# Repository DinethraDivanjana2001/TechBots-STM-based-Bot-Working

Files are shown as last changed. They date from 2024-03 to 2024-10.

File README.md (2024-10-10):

# TechBots-Bot-Working

### Introduction

Our robot was designed to compete in the **Sri Lankan Robotics Challenge 2024**. The robot utilizes a **Raspberry Pi 4B** for color detection and alignment, while the main control logic is handled by an **STM32 microcontroller**. The project combines various hardware and software components to achieve precise control and functionality.

The repository contains the codes used for the microcontroller, the Raspberry Pi, schematics, PCB Design, and 3D enclosure design.

The robot is capable of the following tasks:
* Line detection and following
* Wall color detection
* Floor color detection
* Object detection between a cube and a cylinder
* Shooting a ball into a target

The robot is entirely autonomous.

### Codes

The code for the microcontroller is found under the **STM32 Firmware** directory. There are two versions: one using an **STM32 microcontroller** and the other using an **ESP32**. These codes handle sensor readings and control the robot's movement by controlling the motors.

The **Raspberry Pi Firmware** directory contains the code for color detection and aligning the robot with its target.

### PCB Design

The schematics and PCB design files are found under the **PCB Design** directory. This includes schematics for subcircuits. The robot's PCB is a **4-layer design**.

### Shooter Mechanism

The shooter mechanism is responsible for launching balls into the target. The design, along with related control code, is provided in the **Shooter Mechanism** folder.

### 3D Models

The **3D Models** and renders of the robot are  located in the **3D Designs** directory. The full assembly of the robot is also included.

### Images

Add your images to the appropriate sections below:

1. Robot Design:
   
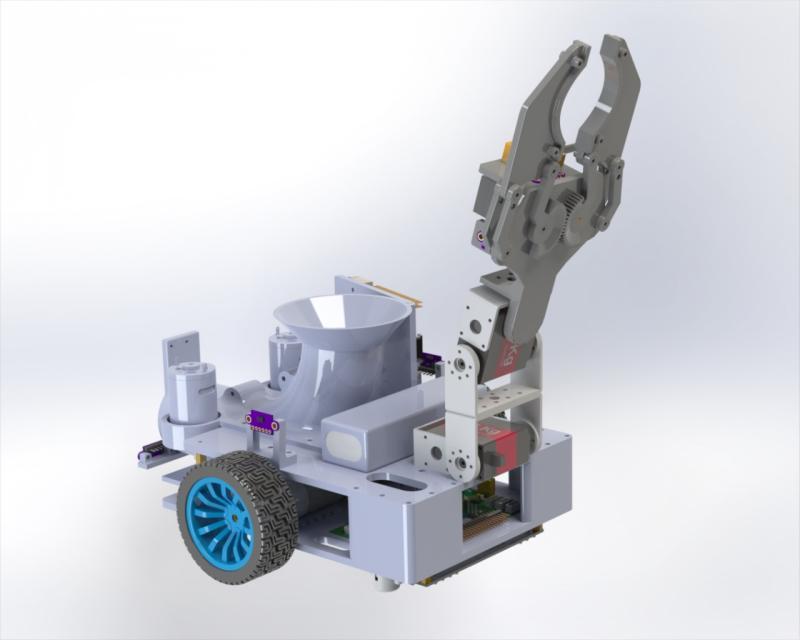
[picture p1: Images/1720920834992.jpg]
Robot Design
   

2. PCB Design:

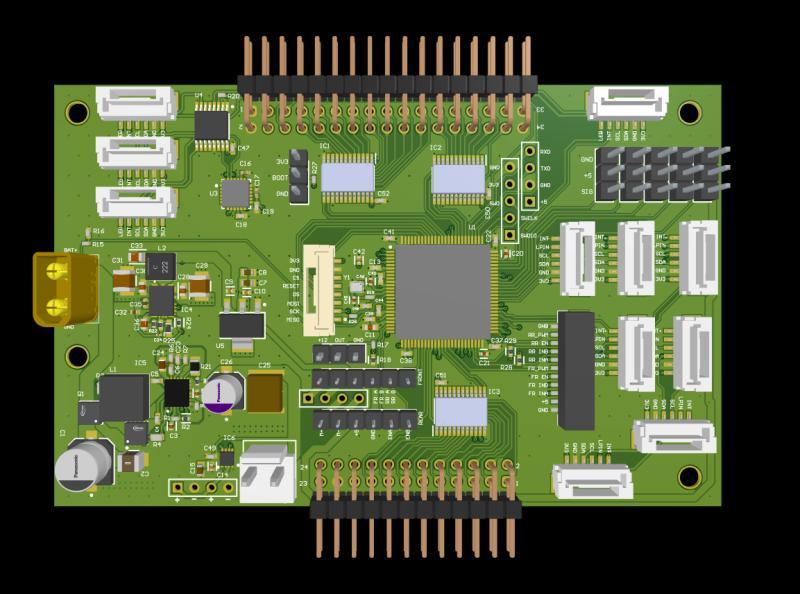
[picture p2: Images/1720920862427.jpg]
PCB Design
   

3. Shooter Mechanism:

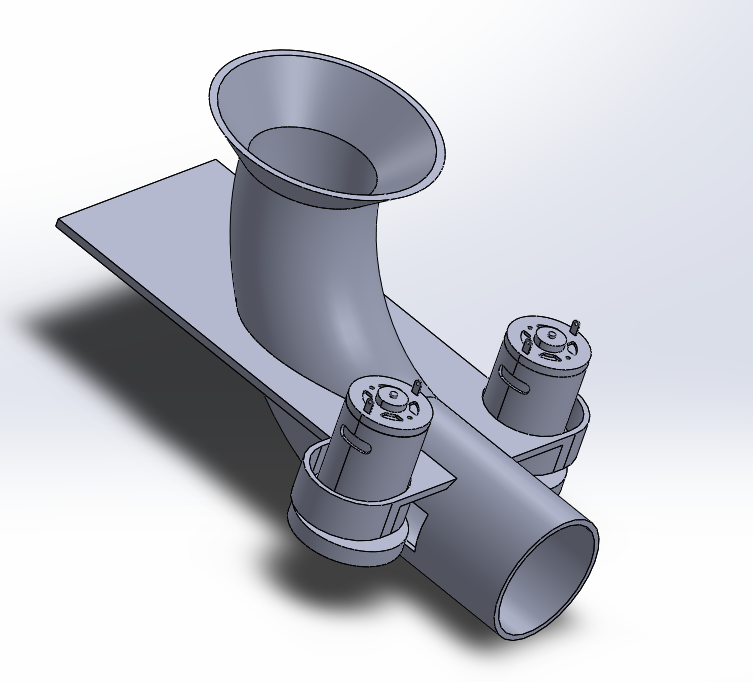
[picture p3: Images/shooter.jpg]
Shooter Mechanism


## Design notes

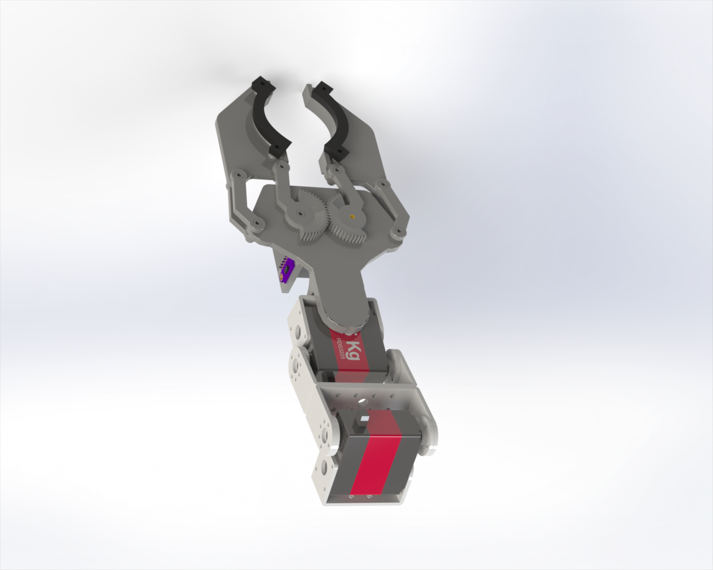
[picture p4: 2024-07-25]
3D designs/3D Renders/Arm bottom.png

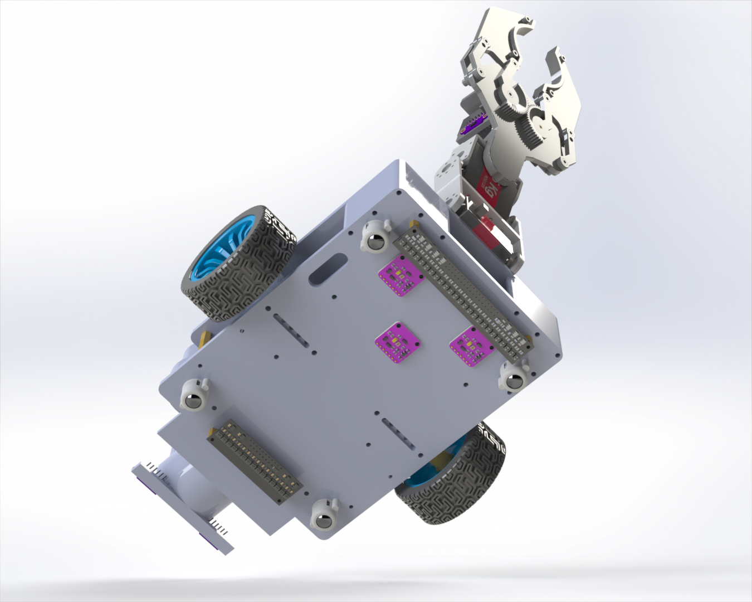
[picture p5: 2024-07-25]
3D designs/3D Renders/Bottom view.png

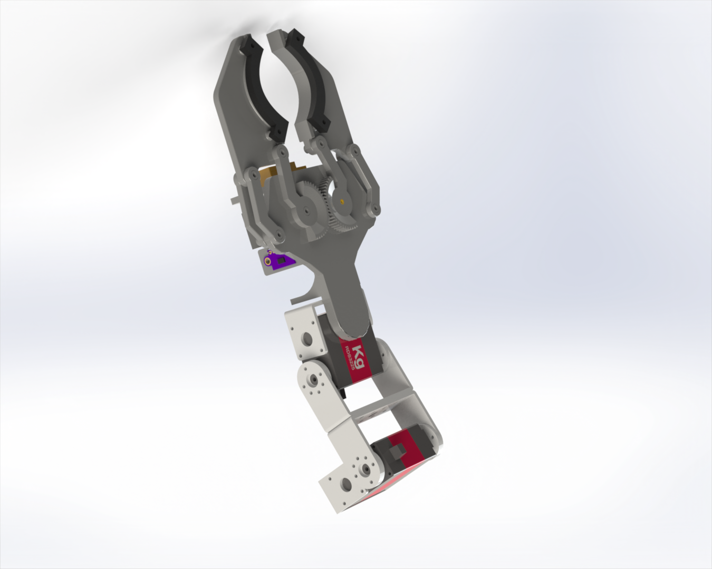
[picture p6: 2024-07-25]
3D designs/3D Renders/Arm side.png

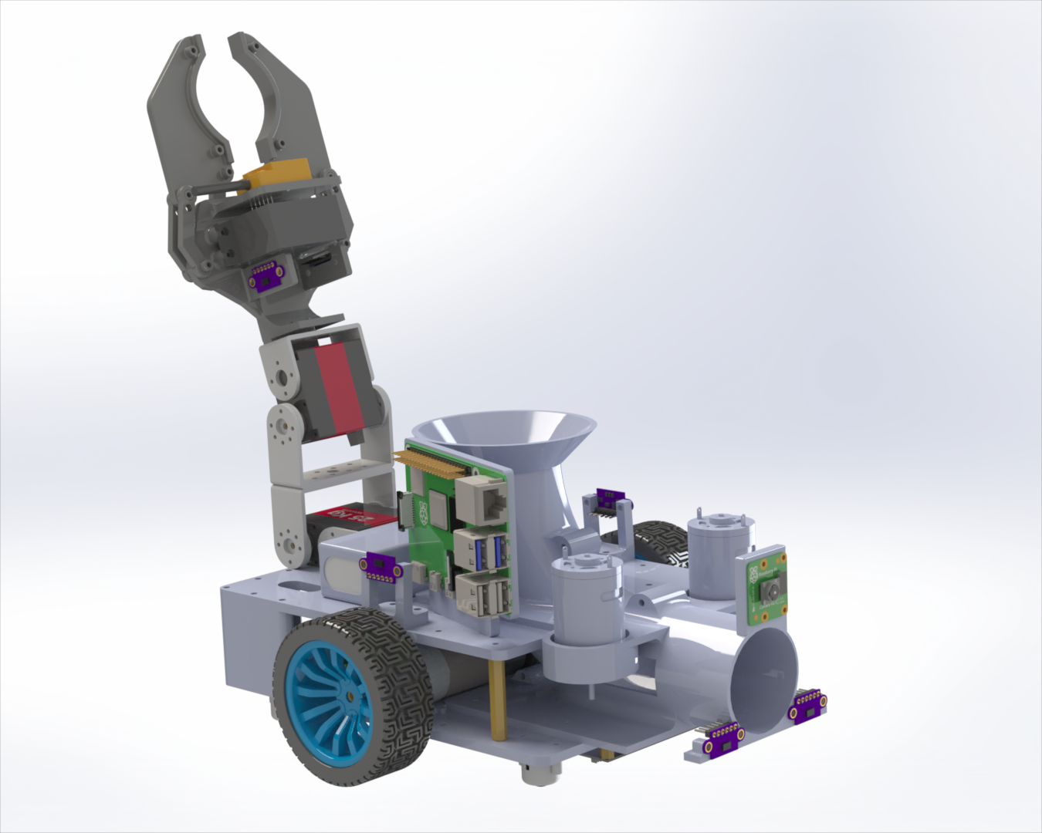
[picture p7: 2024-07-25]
3D designs/3D Renders/Side view 1.png

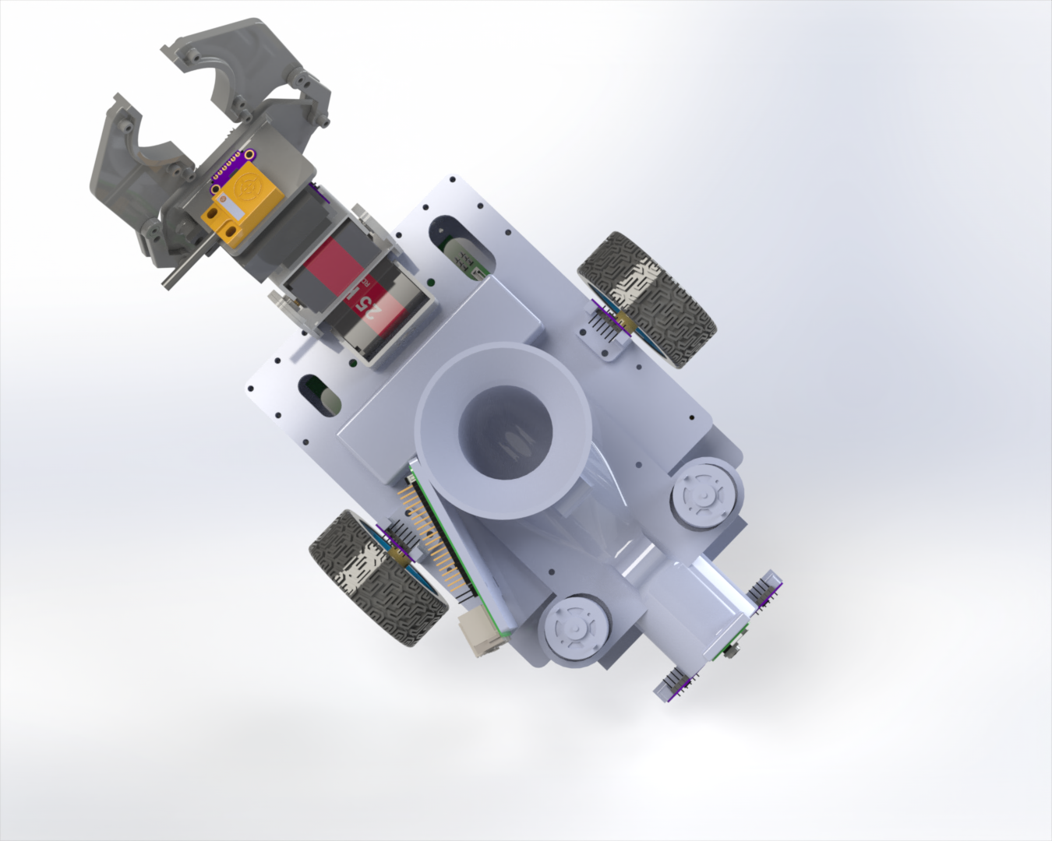
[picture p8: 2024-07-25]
3D designs/3D Renders/Top view.png

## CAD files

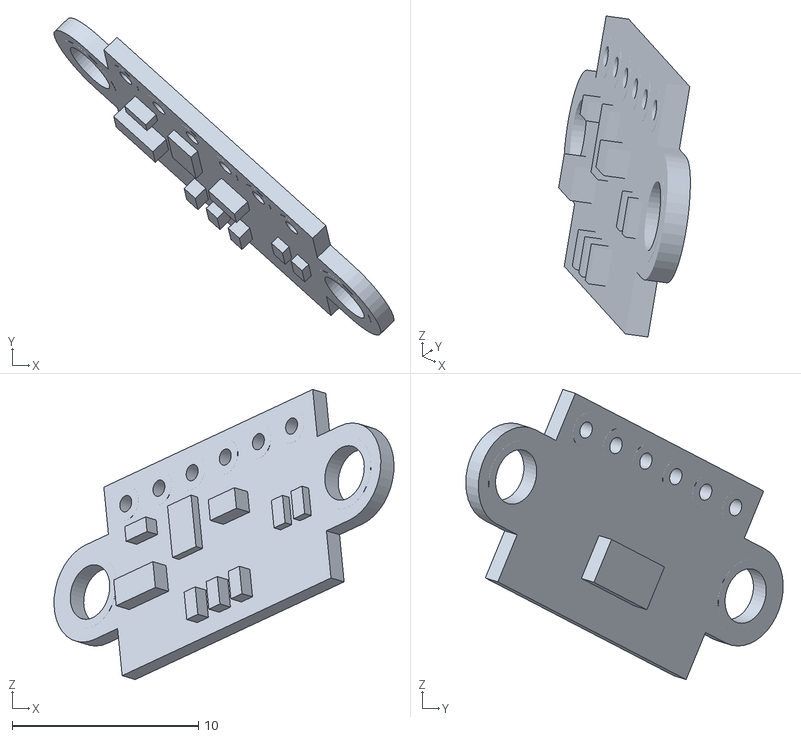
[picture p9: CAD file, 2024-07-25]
3D designs/slrc 3D assembly blender/Assem1.STEP - Full Arm Assembly.STEP-1 vl53l0x.STEP-1 vl53l0x_PCB.STEP-1.STL
18.3 x 17.1 x 15.6

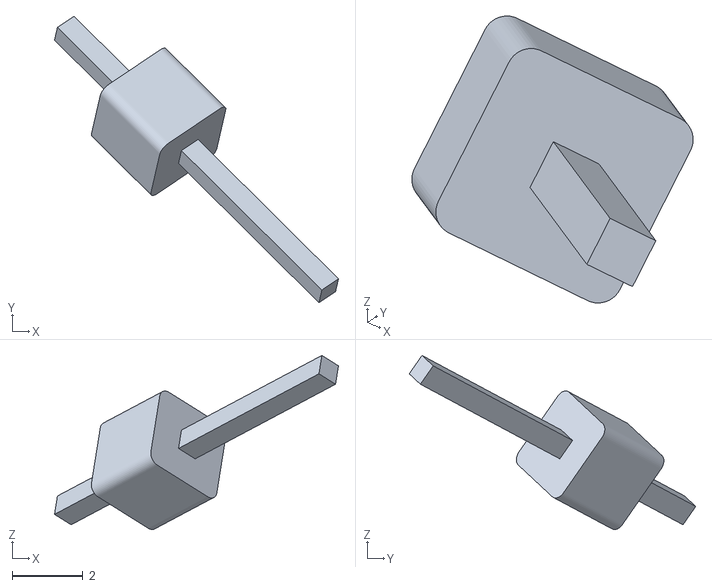
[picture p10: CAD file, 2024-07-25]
3D designs/slrc 3D assembly blender/Assem1.STEP - Tof assembly.STEP-2 vl53l0x.STEP-1 pin_header.STEP-1.STL
8.06 x 8.13 x 4.94

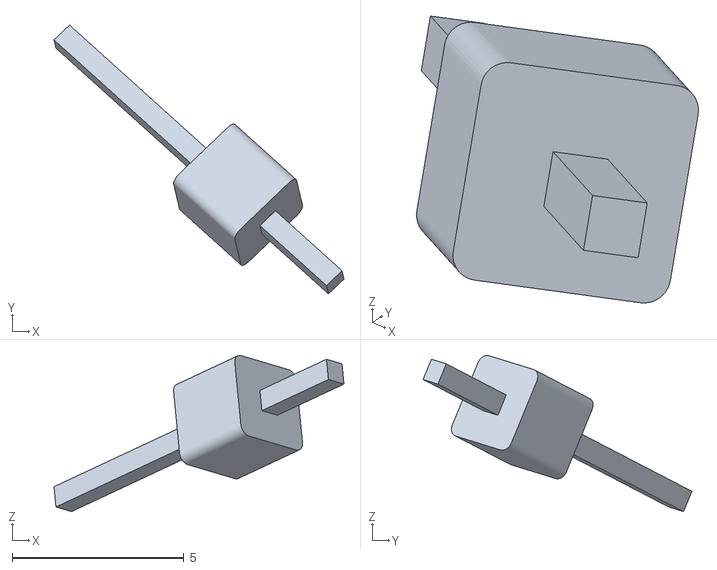
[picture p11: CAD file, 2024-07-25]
3D designs/slrc 3D assembly blender/Assem1.STEP - Full Arm Assembly.STEP-1 vl53l0x.STEP-3 pin_header.STEP-1.STL
8.44 x 7.82 x 4.54

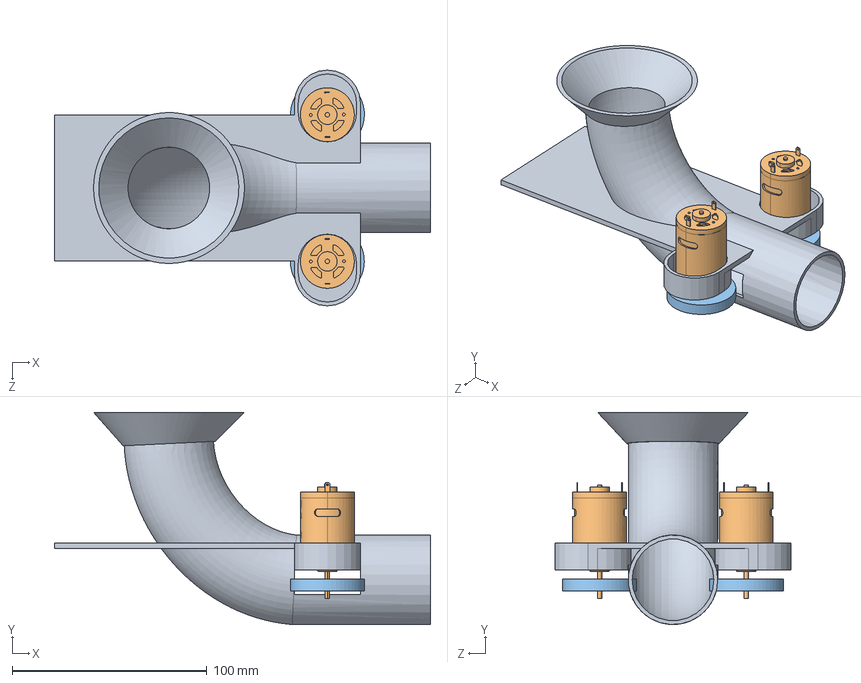
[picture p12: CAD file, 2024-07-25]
Shooter/Solid_works_design/Assmbly.SLDASM
193.2 x 109.0 x 121.2 mm
Shooter
rs380 motor.step x 2
Wheel x 2

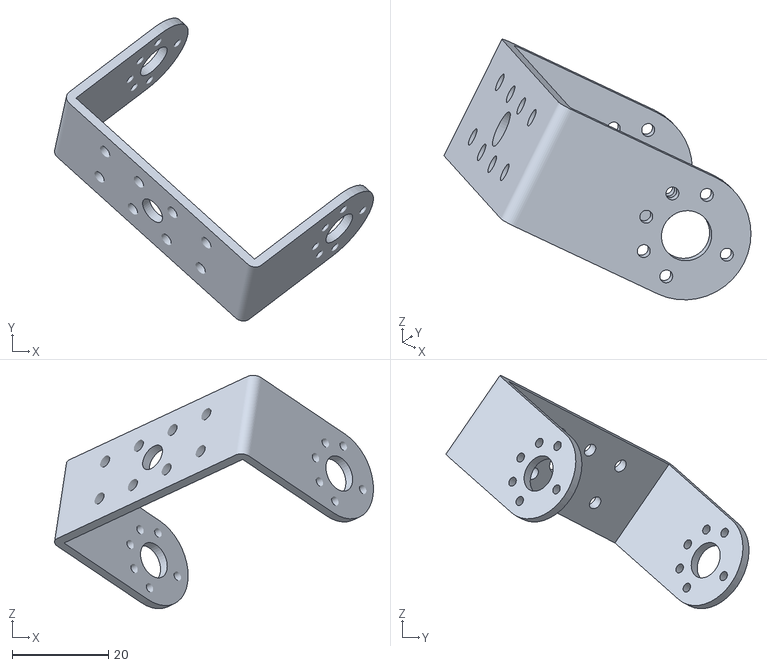
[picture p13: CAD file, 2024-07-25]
3D designs/slrc 3D assembly blender/Assem1.STEP - Full Arm Assembly.STEP-1 RDS3225 v7 support.STEP-1 RDS3225 v7_3^RDS3225 v7 support.STEP-1 Support_large_3^RDS3225 v7_3_RDS3225 v7 support.STEP-1.STL
66.4 x 63.1 x 48.6

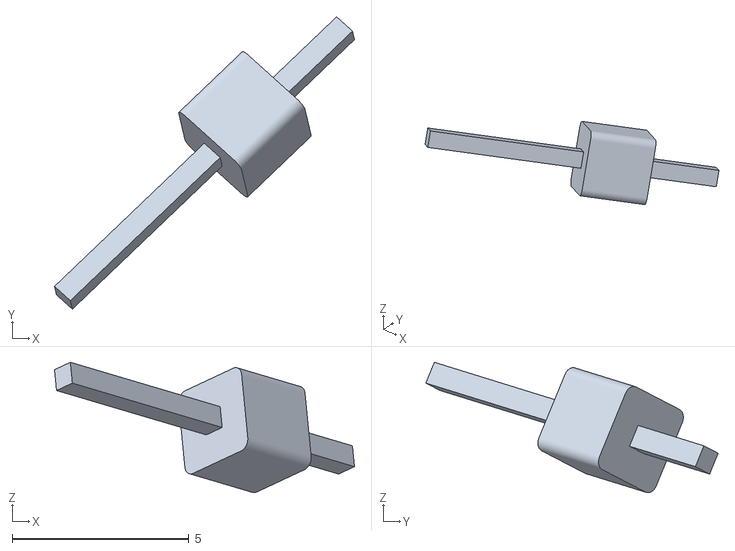
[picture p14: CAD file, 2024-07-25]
3D designs/slrc 3D assembly blender/Assem1.STEP - Full Arm Assembly.STEP-1 vl53l0x.STEP-1 pin_header.STEP-2.STL
8.50 x 8.28 x 3.69

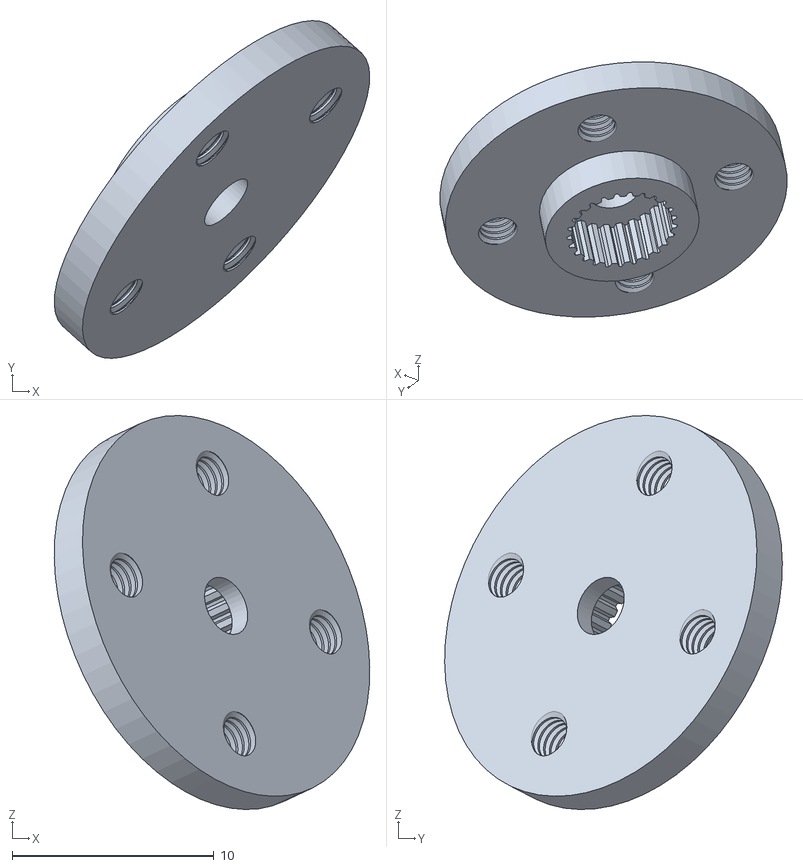
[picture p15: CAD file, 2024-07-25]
3D designs/slrc 3D assembly blender/Assem1.STEP - Full Arm Assembly.STEP-1 RDS3225 v7.STEP-1 RDS3225 v7_3^RDS3225 v7.STEP-1 Wheel_gear_3^RDS3225 v7_3_RDS3225 v7.STEP-1.STL
15.7 x 16.8 x 19.5

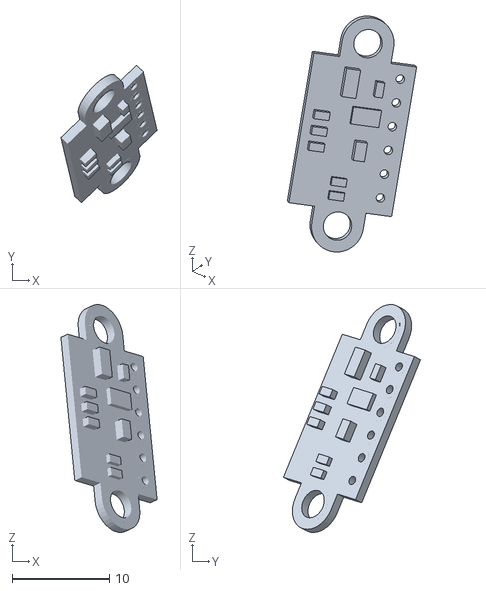
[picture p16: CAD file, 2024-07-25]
3D designs/slrc 3D assembly blender/Assem1.STEP - Full Arm Assembly.STEP-1 vl53l0x.STEP-2 vl53l0x_PCB.STEP-1.STL
9.91 x 14.1 x 23.5

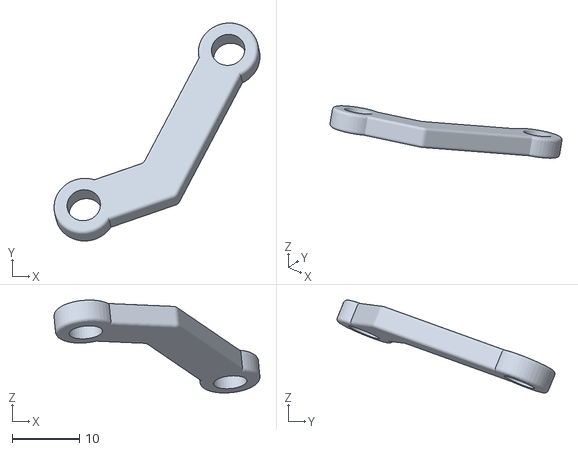
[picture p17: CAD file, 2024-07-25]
3D designs/slrc 3D assembly blender/Assem1.STEP - Full Arm Assembly.STEP-1 Arm gripper new.STEP-4.STL
30.7 x 32.5 x 13.9

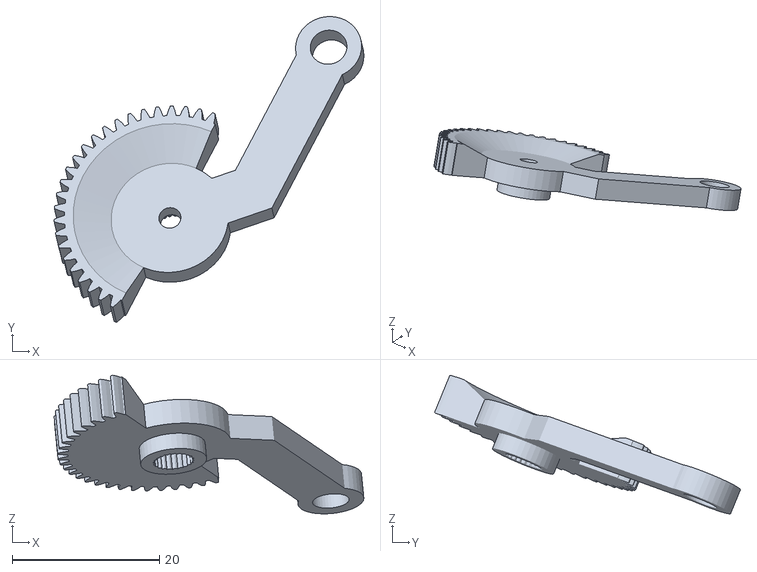
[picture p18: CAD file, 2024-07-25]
3D designs/slrc 3D assembly blender/Assem1.STEP - Full Arm Assembly.STEP-1 Servo gears.STEP-1.STL
42.0 x 41.5 x 18.8

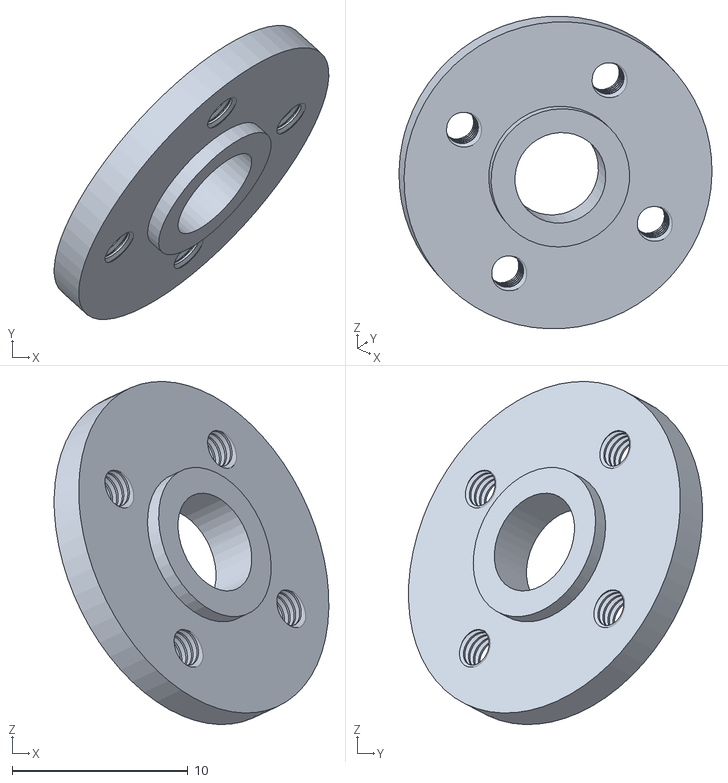
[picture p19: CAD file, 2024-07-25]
3D designs/slrc 3D assembly blender/Assem1.STEP - Full Arm Assembly.STEP-1 RDS3225 v7.STEP-2 RDS3225 v7_3^RDS3225 v7.STEP-1 Wheel_3^RDS3225 v7_3_RDS3225 v7.STEP-1.STL
15.6 x 16.7 x 19.5

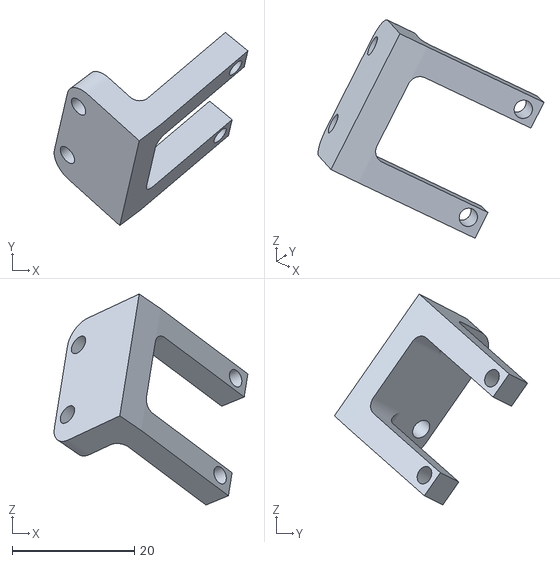
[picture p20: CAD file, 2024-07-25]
3D designs/slrc 3D assembly blender/Assem1.STEP - Tof assembly.STEP-1 New tof mount.STEP-1.STL
31.7 x 31.6 x 34.5

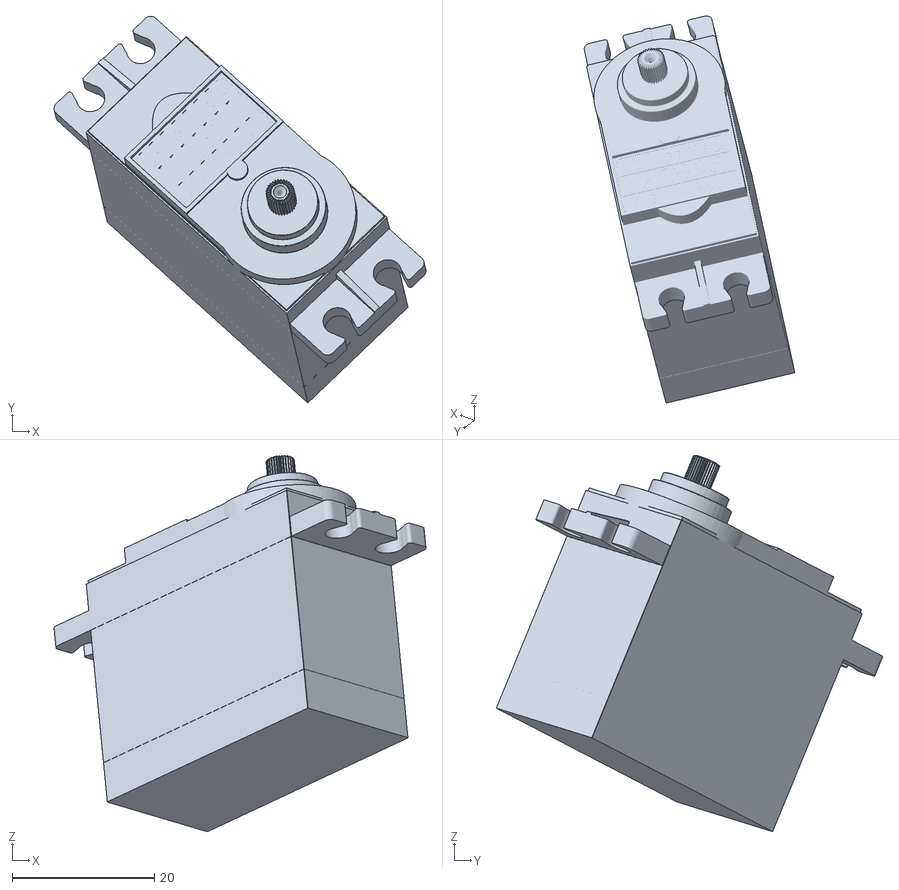
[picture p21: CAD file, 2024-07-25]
3D designs/slrc 3D assembly blender/Assem1.STEP - Full Arm Assembly.STEP-1 Mg995.step.STEP-1.STL
52.4 x 54.4 x 53.0

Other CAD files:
3D designs/slrc 3D assembly blender/Assem1.STEP - Full Arm Assembly.STEP-1 vl53l0x.STEP-1 pin_header.STEP-4.STL
3D designs/slrc 3D assembly blender/Assem1.STEP - Full Arm Assembly.STEP-1 vl53l0x.STEP-3 pin_header.STEP-6.STL
3D designs/slrc 3D assembly blender/Assem1.STEP - Full Arm Assembly.STEP-1 vl53l0x.STEP-2 pin_header.STEP-4.STL
3D designs/slrc 3D assembly blender/Assem1.STEP - Full Arm Assembly.STEP-1 vl53l0x.STEP-2 pin_header.STEP-6.STL
3D designs/slrc 3D assembly blender/Assem1.STEP - Full Arm Assembly.STEP-1 vl53l0x.STEP-2 pin_header.STEP-1.STL
3D designs/slrc 3D assembly blender/Assem1.STEP - Base.STEP-1.STL
3D designs/slrc 3D assembly blender/Assem1.STEP - Even newer spacer.STEP-1.STL
3D designs/slrc 3D assembly blender/Assem1.STEP - Even newer spacer.STEP-2.STL
3D designs/slrc 3D assembly blender/Assem1.STEP - Full Arm Assembly.STEP-1 Arm gripper new.STEP-1.STL
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

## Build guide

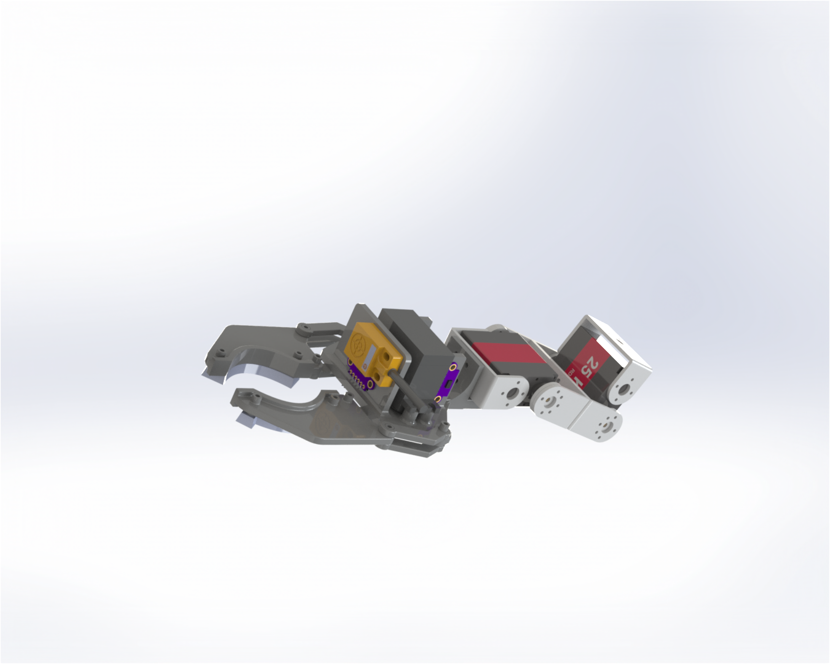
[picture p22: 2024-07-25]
3D designs/3D Renders/Arm assembly 2.png

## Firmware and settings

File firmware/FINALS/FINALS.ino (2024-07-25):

#include <WiFi.h>

#include <Wire.h>
#define TCAADDR 0x70

#include <Adafruit_TCS34725.h>

// Create an instance of the Adafruit_TCS34725 class
Adafruit_TCS34725 tcs = Adafruit_TCS34725(TCS34725_INTEGRATIONTIME_50MS, TCS34725_GAIN_4X);

///////////////////////////////////////////////////////////////////////

#define INA_LEFT 37
#define INB_LEFT 36
#define PWM_LEFT 35

#define INA_RIGHT 40
#define INB_RIGHT 39
#define PWM_RIGHT 38

#define ENC_LA 6
#define ENC_LB 5

#define ENC_RA 15
#define ENC_RB 7

#define LEFT_MOTOR 1
#define RIGHT_MOTOR -1

#define FORWARD 0
#define BACKWARD 1

#define IR_ARRAY_LENGTH 23
#define IR_BACK_ARRAY_LENGTH 23

#define mux_L_sig 16
#define mux_L_s3 17
#define mux_L_s2 18
#define mux_L_s1 21
#define mux_L_s0 47

#define mux_R_sig 19
#define mux_R_s3 20
#define mux_R_s2 10
#define mux_R_s1 11
#define mux_R_s0 12

#define posMaxSpeed 400
#define posMaxBackSpeed 400

#define left 0
#define right 1

#define calibrationButton 48

#define Buzzer 41
///////////////////////////////////////////////////////////////////////

int CalibTime = 0;

int LEVEL = 1;

int box_check = 0;

// PID parametaers for Line Following
bool mode = 0;  // 0 - line , 1 - bend

int endOfCircle = 2;


double Kp = 1.25;
double Ki = 0.0001;
double Kd = 0.18;

double Kp_cent = 7;
double Ki_cent = 0.000;
double Kd_cent = 0.18;

double Kp_Back_cent = 25;
double Ki_Back_cent = 0.000;
double Kd_Back_cent = 0.4;

double Kp_C = 3;
double Ki_C = 0.0001;
double Kd_C = 0.18;

double Kp_Back = 10;
double Ki_Back = 0;
double Kd_Back = 0.4;

double now_time = 0;

float left_sum;
float right_sum;
float right_sensors;
float left_sensors;

float Back_left_sum;
float Back_right_sum;
float Back_right_sensors;
float Back_left_sensors;

int Drive_constant = 400;
int Back_Drive_constant = 300;

int prev_position = 0;
int prev_history_sum = 0;

// Initialize PID variables
double prevError = 0;
double integral = 0;
double derivative = 0;

// Initialize PID variables
double Back_prevError = 0;
double Back_integral = 0;
double Back_derivative = 0;

const int leftMotorChannel = 0;
const int rightMotorChannel = 1;
const int frequency = 10000;
const int resolution = 10;

uint16_t r, g, b, c;

int IR_array[IR_ARRAY_LENGTH];
int Back_IR_array[IR_BACK_ARRAY_LENGTH];
int Ir_thresholds[] = { 1000, 1000, 1000, 1000, 1000, 1000, 1000, 1000, 1000, 1000, 1000, 1000, 1000, 1000, 1000, 1000, 1000, 1000, 1000, 1000, 1000, 1000, 1000 };

int Left_drive = 0;
int Right_drive = 0;

volatile int leftCount = 0;
volatile int rightCount = 0;

int setpoint_L = 312;
int setpoint_R = -312;

// PID parameters for Line Following
double Kp_L = 2;
double Ki_L = 0.000;
double Kd_L = 0.00005;

// PID parameters for Line Following
double Kp_R = 2;
double Ki_R = 0.000;
double Kd_R = 0.00005;

// Initialize PID variables
double prevError_L = 0;
double integral_L = 0;
double derivative_L = 0;

// Initialize PID variables
double prevError_R = 0;
double integral_R = 0;
double derivative_R = 0;

uint32_t nowTime;
bool bendDirection;
int level = 0;
int maxMotorSpeed = 1000;
int maxBackMotorSpeed = 600;

String WALL_COLOR = "BLUE";
String JUNCTION_COLOR = "BLUE";
///////////////////////////////////////////////////////////////////////

void readIRArray();
int readRightMux(int channel);
int readLeftMux(int channel);
void speed(int leftSpeed, int rightSpeed);
void motor(int motor, int direction);

void IRAM_ATTR leftEncoderISR() {
  if (digitalRead(ENC_LB) == HIGH) {
    leftCount++;
  } else {
    leftCount--;
  }
}

void IRAM_ATTR rightEncoderISR() {
  if (digitalRead(ENC_RB) == HIGH) {
    rightCount++;
  } else {
    rightCount--;
  }
}

///////////////////////////////////////////////////////////////////////

void setup() {
  // Initialize serial communication
  Serial.begin(115200);

  WiFi.disconnect(true);
  WiFi.mode(WIFI_OFF);

  pinMode(INA_LEFT, OUTPUT);
  pinMode(INB_LEFT, OUTPUT);
  pinMode(INA_RIGHT, OUTPUT);
  pinMode(INB_RIGHT, OUTPUT);

  pinMode(Buzzer, OUTPUT);

  ledcSetup(leftMotorChannel, frequency, resolution);
  ledcAttachPin(PWM_LEFT, leftMotorChannel);

  ledcSetup(rightMotorChannel, frequency, resolution);
  ledcAttachPin(PWM_RIGHT, rightMotorChannel);

  pinMode(mux_R_s3, OUTPUT);
  pinMode(mux_R_s2, OUTPUT);
  pinMode(mux_R_s1, OUTPUT);
  pinMode(mux_R_s0, OUTPUT);

  pinMode(mux_L_s3, OUTPUT);
  pinMode(mux_L_s2, OUTPUT);
  pinMode(mux_L_s1, OUTPUT);
  pinMode(mux_L_s0, OUTPUT);

  pinMode(ENC_LA, INPUT);
  pinMode(ENC_LB, INPUT);
  pinMode(ENC_RA, INPUT);
  pinMode(ENC_RB, INPUT);

  pinMode(calibrationButton, INPUT);

  attachInterrupt(ENC_LA, leftEncoderISR, RISING);
  attachInterrupt(ENC_RA, rightEncoderISR, RISING);

  Wire.begin();  // Initialize I2C bus
  // Wire.setClock(400000);  // Set I2C clock frequency to 400 kHz

  tcaselect(1);

  // Initialize the sensor
  if (!tcs.begin()) {
    Serial.println("Error initializing TCS34725 sensor!");
    while (1)
      ;  // Hang in case of failure
  }
  Serial.println("TCS34725 sensor initialized successfully!");
  // level = 2; // Remove this. Only for testing purposes

  // calibrate();
}

///////////////////////////////////////////////////////////////////////

void readIRArray() {
  // Loop through channels 0 to 15
  for (int channel = 0; channel < 16; channel++) {
    // int rightValue = readRightMux(channel);
    // Serial.print(" ");
    // Serial.print(rightValue);
    IR_array[channel] = readRightMux(channel) < Ir_thresholds[channel];
  }

  for (int channel = 0; channel <= 6; channel++) {
    // int leftValue = readLeftMux(channel);
    // Serial.print(" ");
    // Serial.print(leftValue);
    IR_array[channel + 16] = readLeftMux(channel) < Ir_thresholds[channel + 16];
  }

  // Serial.println();
}

void readBackIRArray() {

  for (int channel = 7; channel <= 15; channel++) {
    // int leftValue = readLeftMux(channel);
    // Serial.print(" ");
    // Serial.print(leftValue);
    Back_IR_array[channel - 7] = readLeftMux(channel) < 2000;
  }

  // Serial.println();
}

///////////////////////////////////////////////////////////////////////

// Function to read analog value from left mux
int readLeftMux(int channel) {
  digitalWrite(mux_L_s0, bitRead(channel, 0));
  digitalWrite(mux_L_s1, bitRead(channel, 1));
  digitalWrite(mux_L_s2, bitRead(channel, 2));
  digitalWrite(mux_L_s3, bitRead(channel, 3));

  return analogRead(mux_L_sig);
}

///////////////////////////////////////////////////////////////////////

// Function to read analog value from right mux
int readRightMux(int channel) {
  digitalWrite(mux_R_s0, bitRead(channel, 0));
  digitalWrite(mux_R_s1, bitRead(channel, 1));
  digitalWrite(mux_R_s2, bitRead(channel, 2));
  digitalWrite(mux_R_s3, bitRead(channel, 3));

  return analogRead(mux_R_sig);
}

///////////////////////////////////////////////////////////////////////

void speed(int leftSpeed, int rightSpeed) {
  // Set speed for left motor
  ledcWrite(leftMotorChannel, leftSpeed);

  // Set speed for right motor
  ledcWrite(rightMotorChannel, rightSpeed);
}

///////////////////////////////////////////////////////////////////////

void motor(int motor, int direction) {
  if (motor == LEFT_MOTOR) {
    if (direction == FORWARD) {
      digitalWrite(INA_LEFT, HIGH);
      digitalWrite(INB_LEFT, LOW);
    } else if (direction == BACKWARD) {
      digitalWrite(INA_LEFT, LOW);
      digitalWrite(INB_LEFT, HIGH);
    }
  } else if (motor == RIGHT_MOTOR) {
    if (direction == FORWARD) {
      digitalWrite(INA_RIGHT, HIGH);
      digitalWrite(INB_RIGHT, LOW);
    } else if (direction == BACKWARD) {
      digitalWrite(INA_RIGHT, LOW);
      digitalWrite(INB_RIGHT, HIGH);
    }
  }
}

void applyBrakes(int motor) {
  if (motor == LEFT_MOTOR) {
    digitalWrite(INA_LEFT, HIGH);  // Set one terminal high
    digitalWrite(INB_LEFT, HIGH);  // Set the other terminal high
  } else if (motor == RIGHT_MOTOR) {
    digitalWrite(INA_RIGHT, HIGH);  // Set one terminal high
    digitalWrite(INB_RIGHT, HIGH);  // Set the other terminal high
  }
}

double Getabs(double num) {
  if (num > 0) {
    return num;
  } else {
    return -num;
  }
}

////////////////////////////////////takeBend////////////////////////////
void takeBend(bool direction, String mode = "NORMAL") {
  if (millis() < 500) {
    return;
  }
  applyBrakes(RIGHT_MOTOR);
  applyBrakes(LEFT_MOTOR);
  delay(200);

  if (mode == "NORMAL") {
    motor(LEFT_MOTOR, FORWARD);
    motor(RIGHT_MOTOR, FORWARD);
    speed(500, 500);
    delay(200);
  } else if (mode == "EndOfCircle") {
    motor(LEFT_MOTOR, FORWARD);
    motor(RIGHT_MOTOR, FORWARD);
    speed(500, 800);
    delay(200);
  } else if (mode == "BACK") {
    motor(LEFT_MOTOR, BACKWARD);
    motor(RIGHT_MOTOR, BACKWARD);
    speed(500, 500);
    delay(200);
  }

  // Serial.print(leftCount);
  // Serial.print(" : ");
  // Serial.print(rightCount);
  // Serial.print(" : ");
  if (direction) {
    setpoint_L = 370;
    setpoint_R = -370;
  } else {
    setpoint_L = -370;
    setpoint_R = 370;
  }
  leftCount = 0;
  rightCount = 0;


  double nowBendTime = millis();
  while (millis() - nowBendTime < 1000) {

    int leftPos = setpoint_L - leftCount;

    derivative_L = leftPos - prevError_L;
    // added by nirosh
    integral_L = integral_L + leftPos;
    //
    double PID_constant_L = Kp_L * leftPos + Ki_L * integral_L + Kd_L * derivative_L;

    // Serial.print(" pid integral l : ");
    // Serial.print(integral_L);
    // Serial.print(" : ");

    prevError_L = leftPos;

    if (PID_constant_L > posMaxSpeed) PID_constant_L = posMaxSpeed;
    if (PID_constant_L < -posMaxSpeed) PID_constant_L = -posMaxSpeed;

    if (integral_L > 400 / Ki_L) integral_L = 400 / Ki_L;
    if (integral_L < -400 / Ki_L) integral_L = -400 / Ki_L;


    // Serial.print(PID_constant_L);
    // Serial.print(" : ");

    ///////////////////////////////////////////////////////////

    int rightPos = setpoint_R - rightCount;

    derivative_R = rightPos - prevError_R;
    // aded by nirosh
    integral_R = integral_R + rightPos;
    //
    double PID_constant_R = Kp_R * rightPos + Ki_R * integral_R + Kd_R * derivative_R;

    prevError_R = rightPos;

    if (PID_constant_R > posMaxSpeed) PID_constant_R = posMaxSpeed;
    if (PID_constant_R < -posMaxSpeed) PID_constant_R = -posMaxSpeed;

    if (integral_R > 400 / Ki_R) integral_R = 400 / Ki_R;
    if (integral_R < -400 / Ki_R) integral_R = -400 / Ki_R;

    // Serial.println(PID_constant_R);

    if (PID_constant_L > 0) {
      motor(LEFT_MOTOR, FORWARD);  // Set left motor direction to backward
    } else {
      motor(LEFT_MOTOR, BACKWARD);  // Set left motor direction to backward
    }

    if (PID_constant_R > 0) {
      motor(RIGHT_MOTOR, FORWARD);  // Set left motor direction to backward
    } else {
      motor(RIGHT_MOTOR, BACKWARD);  // Set left motor direction to backward
    }

    // applyBrakes(RIGHT_MOTOR);

    // Serial.println(Getabs(PID_constant_L));
    speed(Getabs(PID_constant_L), Getabs(PID_constant_R));
  }
  applyBrakes(RIGHT_MOTOR);
  applyBrakes(LEFT_MOTOR);
  delay(100);
  leftCount = 0;
  rightCount = 0;
  prevError_L = 0;
  integral_L = 0;
  derivative_L = 0;
  prevError_R = 0;
  integral_R = 0;
  derivative_R = 0;
  prevError = 0;
  integral = 0;
  derivative = 0;
}

void CurvelineFollow() {
  readIRArray();

  int array_lit_amount = 0;
  for (int i = 0; i < IR_ARRAY_LENGTH; i++) {
    array_lit_amount += IR_array[i];
  }

  // The following two lines should change with respect to IR array length.

  // // For 8 IR array.
  left_sensors = IR_array[0] + IR_array[1] + IR_array[2] + IR_array[3] + IR_array[4] + IR_array[5] + IR_array[6] + IR_array[7] + IR_array[8] + IR_array[9] + IR_array[10];
  right_sensors = IR_array[12] + IR_array[13] + IR_array[14] + IR_array[15] + IR_array[16] + IR_array[17] + IR_array[18] + IR_array[19] + IR_array[20] + IR_array[21] + IR_array[22];

  left_sum = -54 * IR_array[0] - 39 * IR_array[1] - 36 * IR_array[2] - 33 * IR_array[3] - 29 * IR_array[4] - 24 * IR_array[5] - 20 * IR_array[6] - 15 * IR_array[7] - 12 * IR_array[8] - 5.4 * IR_array[9] - 2.7 * IR_array[10];
  right_sum = 2.7 * IR_array[12] + 5.4 * IR_array[13] + 12 * IR_array[14] + 15 * IR_array[15] + 20 * IR_array[16] + 24 * IR_array[17] + 29 * IR_array[18] + 33 * IR_array[19] + 36 * IR_array[20] + 39 * IR_array[21] + 54 * IR_array[22];
  //Serial.println(left_sum + right_sum);

  int position = left_sum + right_sum;

  derivative = position - prevError;
  // aded by nirosh
  integral = integral + position;
  //
  int PID_constant = Kp_C * position + Ki_C * integral + Kd_C * derivative;

  prevError = position;

  int offset = 0;  // For correcting motor speeds
  Left_drive = Drive_constant + offset - PID_constant;
  Right_drive = Drive_constant - offset + PID_constant;

  // Limiting to 0 - 255 range
  Left_drive = min(max(Left_drive, 0), maxMotorSpeed);
  Right_drive = min(max(Right_drive, 0), maxMotorSpeed);

  prev_position = position;

  speed(Right_drive, Left_drive);  // Set right motor speed to 150
  motor(RIGHT_MOTOR, FORWARD);     // Set right motor direction to forward
  motor(LEFT_MOTOR, FORWARD);      // Set left motor direction to backward

  // for (int i = 0; i < 22; i++) {
  //   Serial.print(IR_array[i]);
  //   Serial.print(" : ");
  // }

  // Serial.print(Left_drive);
  // Serial.print(" : ");
  // Serial.print(Right_drive);
  // Serial.print(" : ");
  // Serial.println();
}
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
void loop() {


  nowTime = micros();

  if (digitalRead(calibrationButton)) calibrate();
  /////////////////////////////////////////////////////////////////////////////////////

  bool COLOR_SCANNED = false;
  bool SQUARE_ELIMINATED = false;
  bool LEVEL1_RIGHT_TURN = false;
  while (LEVEL == 1) {

    if (!COLOR_SCANNED) {
      BacklineFollow();
      //////////decisions on jections and bends////////////
      if (left_sensors + right_sensors > 16) {

        if (millis() - CalibTime < 2000) {
          while (true) {
            readIRArray();
            // // For 8 IR array.
            left_sensors = IR_array[0] + IR_array[1] + IR_array[2] + IR_array[3] + IR_array[4] + IR_array[5] + IR_array[6] + IR_array[7] + IR_array[8] + IR_array[9] + IR_array[10];
            right_sensors = IR_array[12] + IR_array[13] + IR_array[14] + IR_array[15] + IR_array[16] + IR_array[17] + IR_array[18] + IR_array[19] + IR_array[20] + IR_array[21] + IR_array[22];

            if (left_sensors + right_sensors < 10) {
              break;
            }
            motor(RIGHT_MOTOR, BACKWARD);
            motor(LEFT_MOTOR, BACKWARD);
            speed(310, 350);
            // delay(1000);
          }
          applyBrakes(RIGHT_MOTOR);
          applyBrakes(LEFT_MOTOR);
          delay(100);
          motor(RIGHT_MOTOR, BACKWARD);
          motor(LEFT_MOTOR, BACKWARD);
          speed(310, 350);
          delay(100);
          SQUARE_ELIMINATED = true;
        } else if (IR_array[0] && IR_array[22]) {
          // level++;
          applyBrakes(RIGHT_MOTOR);
          applyBrakes(LEFT_MOTOR);
          delay(5000);
          motor(RIGHT_MOTOR, BACKWARD);
          motor(LEFT_MOTOR, BACKWARD);
          speed(500, 500);
          delay(500);
          // takeBend(left);
        } else {

          // box_check = 2;
          applyBrakes(RIGHT_MOTOR);
          applyBrakes(LEFT_MOTOR);
          delay(5000);
          motor(RIGHT_MOTOR, BACKWARD);
          motor(LEFT_MOTOR, BACKWARD);
          speed(500, 500);
          delay(300);
          // takeBend(left);
          // takeBend(left);
        }
      } else if (SQUARE_ELIMINATED && IR_array[0] && (IR_array[1] + IR_array[2] + IR_array[3] + IR_array[4] + IR_array[5] + IR_array[6] + IR_array[7]) >= 5 && (IR_array[21] + IR_array[20] + IR_array[19] + IR_array[18] + IR_array[17]) < 5) {
        // Serial.println("Left");
        applyBrakes(RIGHT_MOTOR);
        applyBrakes(LEFT_MOTOR);
        delay(100);
        takeBend(left);
      } else if (SQUARE_ELIMINATED && IR_array[22] && (IR_array[21] + IR_array[20] + IR_array[19] + IR_array[18] + IR_array[17] + IR_array[16] + IR_array[15]) >= 5 && (IR_array[0] + IR_array[1] + IR_array[2] + IR_array[3] + IR_array[4]) < 5) {
        // Serial.println("Right");
        applyBrakes(RIGHT_MOTOR);
        applyBrakes(LEFT_MOTOR);
        delay(100);
        Serial.print("WALL");
        int WALL_Time = millis();
        digitalWrite(Buzzer, HIGH);
        while (millis() - WALL_Time < 2000) {
          if (Serial.available() > 0) {
            String message = Serial.readStringUntil('\n');
            if (message == "GREEN detected") {
              WALL_COLOR = "GREEN";
              break;
            } else if (message == "BLUE detected") {
              WALL_COLOR = "BLUE";
              break;
            }
          }
        }
        digitalWrite(Buzzer, LOW);
        takeBend(right);
        COLOR_SCANNED = true;
      }
    } else {
      lineFollow();
      //////////decisions on jections and bends////////////
      if (left_sensors + right_sensors > 18) {
        // level++;
        applyBrakes(RIGHT_MOTOR);
        applyBrakes(LEFT_MOTOR);
        beep(10);
        delay(100);
        takeBend(left);
        LEVEL++;
      } else if (LEVEL1_RIGHT_TURN && IR_array[0] && (IR_array[1] + IR_array[2] + IR_array[3] + IR_array[4] + IR_array[5] + IR_array[6] + IR_array[7]) >= 5 && (IR_array[21] + IR_array[20] + IR_array[19] + IR_array[18] + IR_array[17]) < 5) {
        // Serial.println("Left");
        takeBend(left);
      } else if (!LEVEL1_RIGHT_TURN && IR_array[22] && (IR_array[21] + IR_array[20] + IR_array[19] + IR_array[18] + IR_array[17] + IR_array[16] + IR_array[15]) >= 5 && (IR_array[0] + IR_array[1] + IR_array[2] + IR_array[3] + IR_array[4]) < 5) {
        // Serial.println("Right");
        takeBend(right);
        LEVEL1_RIGHT_TURN = true;
      }
    }
  }

  bool COLOR_JUNCTION = false;
  while (LEVEL == 2) {
    lineFollow();
    //////////decisions on jections and bends////////////
    if (left_sensors + right_sensors > 16) {
      // level++;
      motor(RIGHT_MOTOR, FORWARD);
      motor(LEFT_MOTOR, FORWARD);
      speed(400, 400);
      delay(150);
      applyBrakes(RIGHT_MOTOR);
      applyBrakes(LEFT_MOTOR);
      delay(100);
      if (!COLOR_JUNCTION) {
        beep(2);
        int count = 0;
        int Green = 0;
        int Blue = 0;
        while (count <= 100) {
          digitalWrite(Buzzer, HIGH);
          tcs.getRawData(&r, &g, &b, &c);
          Green += g;
          Blue += b;
          count++;
        }
        digitalWrite(Buzzer, LOW);
        if (b > g) {
          JUNCTION_COLOR = "BLUE";
          beep(5);
        } else {
          JUNCTION_COLOR = "GREEN";
          beep(2);
        }
        if (JUNCTION_COLOR == WALL_COLOR) {
          takeBend(left);
        } else {
          takeBend(right);
        }

        COLOR_JUNCTION = true;
      } else {
        LEVEL++;
        beep(10);
        takeBend(right);
      }
    } else if (IR_array[0] && (IR_array[1] + IR_array[2] + IR_array[3] + IR_array[4] + IR_array[5] + IR_array[6] + IR_array[7]) >= 5 && (IR_array[21] + IR_array[20] + IR_array[19] + IR_array[18] + IR_array[17]) < 5) {
      // Serial.println("Left");
      takeBend(left);
    } else if (IR_array[22] && (IR_array[21] + IR_array[20] + IR_array[19] + IR_array[18] + IR_array[17] + IR_array[16] + IR_array[15]) >= 5 && (IR_array[0] + IR_array[1] + IR_array[2] + IR_array[3] + IR_array[4]) < 5) {
      // Serial.println("Right");
      takeBend(right);
    }
  }

  bool OUT_OF_CIRCLE = false;
  bool FIRST_TURN = false;
  bool Varience_SENT = false;
  while (LEVEL == 3) {
    if (JUNCTION_COLOR != WALL_COLOR) {
      if (OUT_OF_CIRCLE) {
        lineFollow();
      } else {
        CurvelineFollow();
        if (!Varience_SENT) {
          Serial.println("variance");
          Varience_SENT = true;
        }
      }
      if (FIRST_TURN && OUT_OF_CIRCLE && left_sensors + right_sensors > 16) {
        // level++;
        applyBrakes(RIGHT_MOTOR);
        applyBrakes(LEFT_MOTOR);
        delay(100);

        LEVEL++;
        beep(15);
        takeBend(left);

      } else if (OUT_OF_CIRCLE && IR_array[0] && (IR_array[1] + IR_array[2] + IR_array[3] + IR_array[4] + IR_array[5] + IR_array[6] + IR_array[7]) >= 5 && (IR_array[21] + IR_array[20] + IR_array[19] + IR_array[18] + IR_array[17]) < 5) {
        // Serial.println("Left");
        takeBend(left);
        FIRST_TURN = true;
        beep(3);
      } else if (!FIRST_TURN && IR_array[22] && IR_array[21] && !IR_array[0]) {
        // Serial.println("Right");
        takeBend(right);
        OUT_OF_CIRCLE = true;
        beep(3);
      }
    } else {
      if (OUT_OF_CIRCLE) {
        lineFollow();
      } else {
        CurvelineFollow();
      }
      if (FIRST_TURN && OUT_OF_CIRCLE && left_sensors + right_sensors > 16) {
        // level++;
        applyBrakes(RIGHT_MOTOR);
        applyBrakes(LEFT_MOTOR);
        delay(100);

        LEVEL++;
        beep(15);
        takeBend(right);

      } else if (OUT_OF_CIRCLE && IR_array[22] && IR_array[21] && !IR_array[0]) {
        // Serial.println("Left");
        takeBend(right);
        FIRST_TURN = true;
        beep(3);
      } else if (!FIRST_TURN && IR_array[22] && IR_array[21] && !IR_array[0]) {
        // Serial.println("Right");
        takeBend(right);
        OUT_OF_CIRCLE = true;
        beep(3);
      }
    }
  }
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

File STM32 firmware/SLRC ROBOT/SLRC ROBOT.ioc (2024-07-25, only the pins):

Mcu.UserName=STM32F405VGTx
PA0-WKUP.GPIO_Label=RR_ENCODER_A
PA0-WKUP.Signal=S_TIM2_CH1_ETR
PA1.GPIO_Label=RR_ENCODER_B
PA1.Signal=S_TIM2_CH2
PA11.GPIO_Label=CLR_INT_1
PA11.Signal=GPXTI11
PA12.GPIO_Label=CLR_LED_1
PA12.Signal=GPIO_Output
PA13.Signal=SYS_JTMS-SWDIO
PA14.Signal=SYS_JTCK-SWCLK
PA15.GPIO_Label=FR_ARRAY_ODD
PA15.Signal=GPIO_Output
PA2.GPIO_Label=SHOOTER_PWM
PA2.Signal=S_TIM9_CH1
PA3.GPIO_Label=PROX_IN
PA3.Signal=GPXTI3
PA5.Signal=SPI1_SCK
PA6.GPIO_Label=FR_ENCODER_A
PA6.Signal=S_TIM3_CH1
PA7.GPIO_Label=FR_ENCODER_B
PA7.Signal=S_TIM3_CH2
PA8.GPIO_Label=TOF_LPIN_2
PA8.Signal=GPIO_Output
PA9.GPIO_Label=TOF_INT_2
PA9.Signal=GPXTI9
PB0.GPIO_Label=RR_ARR_OUT
PB0.Signal=ADCx_IN8
PB1.GPIO_Label=RR_ARRAY_MUX_1
PB1.Signal=GPIO_Output
PB10.Signal=I2C2_SCL
PB11.Signal=I2C2_SDA
PB12.GPIO_Label=FR_INA
PB12.Signal=GPIO_Output
PB13.GPIO_Label=FR_INB
PB13.Signal=GPIO_Output
PB14.GPIO_Label=RR_INA
PB14.Signal=GPIO_Output
PB15.GPIO_Label=RR_INB
PB15.Signal=GPIO_Output
PB2.GPIO_Label=RR_ARRAY_MUX_2
PB2.Signal=GPIO_Output
PB3.Signal=SYS_JTDO-SWO
PB4.Signal=SPI1_MISO
PB5.Signal=SPI1_MOSI
PB6.GPIO_Label=LCD_DS
PB6.Signal=GPIO_Output
PB7.GPIO_Label=LCD_RESET
PB7.Signal=GPIO_Output
PB8.GPIO_Label=LCD_CS
PB8.Signal=GPIO_Output
PC0.GPIO_Label=FR_ARRAY_OUTA
PC0.Signal=ADCx_IN10
PC1.GPIO_Label=FR_ARRAY_OUTB
PC1.Signal=ADCx_IN11
PC10.GPIO_Label=BLUTOOTH_TX
PC10.Signal=UART4_TX
PC11.GPIO_Label=BLUTOOTH_RX
PC11.Signal=UART4_RX
PC12.GPIO_Label=FR_ARRAY_EVEN
PC12.Signal=GPIO_Output
PC2.GPIO_Label=BAT_MEASURE
PC2.Signal=ADCx_IN12
PC4.GPIO_Label=RR_ARRAY_ODD
PC4.Signal=GPIO_Output
PC5.GPIO_Label=RR_ARRAY_EVEN
PC5.Signal=GPIO_Output
PC6.GPIO_Label=SERVO_4
PC6.Signal=S_TIM8_CH1
PC7.GPIO_Label=SERVO_3
PC7.Signal=S_TIM8_CH2
PC8.GPIO_Label=SERVO_2
PC8.Signal=S_TIM8_CH3
PC9.GPIO_Label=SERVO_1
PC9.Signal=S_TIM8_CH4
PD0.GPIO_Label=FR_ARRAY_SB2
PD0.Signal=GPIO_Output
PD1.GPIO_Label=FR_ARRAY_SB3
PD1.Signal=GPIO_Output
PD10.GPIO_Label=TOF_INT_5
PD10.Signal=GPXTI10
PD11.GPIO_Label=TOF_LPIN_4
PD11.Signal=GPIO_Output
PD12.GPIO_Label=TOF_INT_4
PD12.Signal=GPXTI12
PD13.GPIO_Label=SERVO_5
PD13.Signal=S_TIM4_CH2
PD14.GPIO_Label=TOF_LPIN_3
PD14.Signal=GPIO_Output
PD15.GPIO_Label=TOF_INT_3
PD15.Signal=GPXTI15
PD2.GPIO_Label=FR_ARRAY_SB0
PD2.Signal=GPIO_Output
PD3.GPIO_Label=FR_ARRAY_SB1
PD3.Signal=GPIO_Output
PD4.GPIO_Label=FR_ARRAY_SA0
PD4.Signal=GPIO_Output
PD5.GPIO_Label=FR_ARRAY_SA1
PD5.Signal=GPIO_Output
PD6.GPIO_Label=FR_ARRAY_SA2
PD6.Signal=GPIO_Output
PD7.GPIO_Label=FR_ARRAY_SA3
PD7.Signal=GPIO_Output
PD9.GPIO_Label=TOF_LPIN_5
PD9.Signal=GPIO_Output
PE0.GPIO_Label=CLR_INT_2
PE0.Signal=GPXTI0
PE1.GPIO_Label=CLR_LED_2
PE1.Signal=GPIO_Output
PE11.GPIO_Label=RR_MOTOR_PWM
PE11.Signal=S_TIM1_CH2
PE12.GPIO_Label=TOF_LPIN_1
PE12.Signal=GPIO_Output
PE13.GPIO_Label=TOF_INT_1
PE13.Signal=GPXTI13
PE14.GPIO_Label=TOF_LPIN_6
PE14.Signal=GPXTI14
PE15.GPIO_Label=TOF_INT_6
PE15.Signal=GPIO_Output
PE2.GPIO_Label=CLR_INT_4
PE2.Signal=GPXTI2
PE3.GPIO_Label=CLR_LED_4
PE3.Signal=GPIO_Output
PE4.GPIO_Label=CLR_INT_3
PE4.Signal=GPIO_Output
PE5.GPIO_Label=CLR_LED_3
PE5.Signal=GPIO_Output
PE6.GPIO_Label=IMU_INT
PE6.Signal=GPXTI6
PE7.GPIO_Label=RR_ARRAY_MUX_3
PE7.Signal=GPIO_Output
PE8.GPIO_Label=RR_ARRAY_MUX_4
PE8.Signal=GPIO_Output
PE9.GPIO_Label=FR_MOTOR_PWM
PE9.Signal=S_TIM1_CH1
PH0-OSC_IN.Signal=RCC_OSC_IN
PH1-OSC_OUT.Signal=RCC_OSC_OUT

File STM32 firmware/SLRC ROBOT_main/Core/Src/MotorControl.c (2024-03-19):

/*
 * MotorControl.c
 *
 *  Created on: Mar 19, 2024
 *      Author: yasir
 */

#include "main.h"
#include "stm32f4xx_hal.h"
#include "MotorControl.h"

extern TIM_HandleTypeDef htim1;

void speed(int Left, int Right){
	  __HAL_TIM_SET_COMPARE(&htim1,FR_MOTOR_PWM,Right);
	  __HAL_TIM_SET_COMPARE(&htim1,RR_MOTOR_PWM,Left);
}

void motor(int motor,int direction){
	if (motor == 0){
		if (direction == 0){
			HAL_GPIO_WritePin(RR_INB_GPIO_Port, RR_INB_Pin, 0);
			HAL_GPIO_WritePin(RR_INA_GPIO_Port, RR_INA_Pin, 1);
		}else{
			HAL_GPIO_WritePin(RR_INB_GPIO_Port, RR_INB_Pin, 1);
			HAL_GPIO_WritePin(RR_INA_GPIO_Port, RR_INA_Pin, 0);
		}
	}else{
		if (direction == 1){
			HAL_GPIO_WritePin(FR_INB_GPIO_Port, FR_INB_Pin, 0);
			HAL_GPIO_WritePin(FR_INA_GPIO_Port, FR_INA_Pin, 1);
		}else{
			HAL_GPIO_WritePin(FR_INB_GPIO_Port, FR_INB_Pin, 1);
			HAL_GPIO_WritePin(FR_INA_GPIO_Port, FR_INA_Pin, 0);
		}
	}
}

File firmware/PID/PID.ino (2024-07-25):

#include <EEPROM.h>
#include "Adafruit_VL53L0X.h"

// ========== LINE_COLOR DEFINITION ==========
const String LINE_COLOR = "WHITE";

int LEVEL = 1;

// Define the size of the array and the EEPROM address to start writing data
const int arraySize = 8;      // Adjust this based on your array size
const int eepromAddress = 0;  // EEPROM address where you want to start writing

const int inputCalib = 7;  // Pin 7 is connected to your input device

float cylinder_variance = 0;

int col = 1;

// PID parameters for Line Following
double Kp = 5;
double Ki = 0;
double Kd = 0.1;

// PID parameters for Line Following
double Kp_circle = 3;
double Ki_circle = 0;
double Kd_circle = 0.3
;

double now_time = 0; 

float left_sum;
float right_sum;
float right_sensors;
float left_sensors;

int Drive_constant = 100;

// Initialize PID variables
double prevError = 0;
double integral = 0;
double derivative = 0;

int Ir_thresholds[] = { 300, 300, 100, 100, 100, 105, 400, 400 };

// define right motor enable pin is 3 and left 2
#define GREEN_LED 6
#define BLUE_LED 5

#define ENR 3
#define ENL 2

#define Motor_Right_Forward 26
#define Motor_Right_Backward 28
#define Motor_Left_Forward 22
#define Motor_Left_Backward 24

// Motor and Direction Definitions
#define RIGHT_MOTOR 1
#define LEFT_MOTOR 2
#define FORWARD 1
#define BACKWARD 2

#define magnet 9

#define Buzzer 11

// IR_array 8 space empty array
#define IR_ARRAY_LENGTH 12
int IR_array[IR_ARRAY_LENGTH];
int calibrate_array_size = IR_ARRAY_LENGTH - 4;

int Threshold = 100;

int prev_position = 0;
int prev_history_sum = 0;


long count = 0;      // Number of observations
float mean = 0;      // Running mean
float M2 = 0;        // Sum of squares of differences from the current mean
float variance = 0;  // Variance

// address we will assign if dual sensor is present
#define LOX1_ADDRESS 0x33
#define LOX2_ADDRESS 0x30

// set the pins to shutdown
#define SHT_LOX1 10
#define SHT_LOX2 39

// objects for the vl53l0x
Adafruit_VL53L0X lox1 = Adafruit_VL53L0X();
Adafruit_VL53L0X lox2 = Adafruit_VL53L0X();

// this holds the measurement
VL53L0X_RangingMeasurementData_t measure1;
VL53L0X_RangingMeasurementData_t measure2;
uint16_t side_tof;
uint16_t front_tof;


void setup() {
  // put your setup code here, to run once:

  Serial.begin(115200);

  pinMode(Motor_Right_Forward, OUTPUT);
  pinMode(Motor_Right_Backward, OUTPUT);
  pinMode(Motor_Left_Forward, OUTPUT);
  pinMode(Motor_Left_Backward, OUTPUT);

  pinMode(A0, INPUT);
  pinMode(A2, INPUT);
  pinMode(A1, INPUT);
  pinMode(A3, INPUT);

  pinMode(inputCalib, INPUT);

  pinMode(magnet, OUTPUT);
  pinMode(Buzzer, OUTPUT);

  pinMode(SHT_LOX1, OUTPUT);
  pinMode(SHT_LOX2, OUTPUT);

  pinMode(BLUE_LED, OUTPUT);
  pinMode(GREEN_LED, OUTPUT);
  

  Serial.println(F("Shutdown pins inited..."));

  digitalWrite(SHT_LOX1, LOW);
  digitalWrite(SHT_LOX2, LOW);

  Serial.println(F("Both in reset mode...(pins are low)"));
  setID();

  for (int i = 0; i < calibrate_array_size; i++) {
    // Ir_thresholds[i] = EEPROM.read(i)*4;
    EEPROM.get(i * sizeof(int), Ir_thresholds[i]);
  }

  Serial.print("int IR_thresholds[] = {");
  for (int i = 0; i < calibrate_array_size; i++) {
    Serial.print(Ir_thresholds[i]);
    Serial.print(", ");
  }
  Serial.println("};    ");

  calibrate();

  trigMagnet(false);

  beep(5);

  while (true) {
    speed(RIGHT_MOTOR, 100);      // Set right motor speed to 150
    motor(RIGHT_MOTOR, FORWARD);  // Set right motor direction to forward

    speed(LEFT_MOTOR, 100);      // Set left motor speed to 200
    motor(LEFT_MOTOR, FORWARD);  // Set left motor direction to backward

    readIRArray();
    if (sensorSum() < 7) {
      Serial.println("ENTERED PID");
      delay(500);
      break;
    }
  }
}

int temp = 0;
int Left_drive = 0;
int Right_drive = 0;

bool task1_color = false;

void loop() {

  //  if(digitalRead(inputCalib) == 1) calibrate();

  if (LEVEL == 1) TASK1();
  if (LEVEL == 2) TASK2();

  if (LEVEL == 3) TASK3();
  if (LEVEL == 4) TASK4();
  if (LEVEL == 5) TASK5();

  // speed(RIGHT_MOTOR, 100); // Set right motor speed to 150
  // motor(RIGHT_MOTOR, FORWARD); // Set right motor direction to forward

  // speed(LEFT_MOTOR, 100); // Set left motor speed to 200
  // motor(LEFT_MOTOR, FORWARD); // Set left motor direction to backward
  // delay(1000);

  // trigMagnet(true);
  // speed(RIGHT_MOTOR, 00); // Set right motor speed to 150
  // motor(RIGHT_MOTOR, FORWARD); // Set right motor direction to forward

  // speed(LEFT_MOTOR, 000); // Set left motor speed to 200
  // motor(LEFT_MOTOR, FORWARD); // Set left motor direction to backward
  // delay(1000);

  // speed(RIGHT_MOTOR, 100); // Set right motor speed to 150
  // motor(RIGHT_MOTOR, BACKWARD); // Set right motor direction to forward

  // speed(LEFT_MOTOR, 100); // Set left motor speed to 200
  // motor(LEFT_MOTOR, BACKWARD); // Set left motor direction to backward
  // delay(2000);

  // trigMagnet(false);
  // speed(RIGHT_MOTOR, 00); // Set right motor speed to 150
  // motor(RIGHT_MOTOR, FORWARD); // Set right motor direction to forward

  // speed(LEFT_MOTOR, 000); // Set left motor speed to 200
  // motor(LEFT_MOTOR, FORWARD); // Set left motor direction to backward
  // delay(1000);
  // delay(1000);
  // Example usage
  // lineFollowVarience();

  // if (IR_array[11] == 1){
  //   speed(255,255);
  //   motor(LEFT_MOTOR, FORWARD);
  //   motor(RIGHT_MOTOR, FORWARD);
  //   delay(500);
  //   speed(0,255);
  //   motor(LEFT_MOTOR, BACKWARD);
  //   motor(RIGHT_MOTOR, FORWARD);
  //   delay(1000);
  //   speed(2,0);
  //   speed(1,0);
  //   delay(1000);
  // }



  // // You can adjust speed and direction as needed
  // delay(1000); // Delay for 1 second
}

// Function to control motor speed
void speed(int motor, int speed) {
  if (motor == RIGHT_MOTOR) {
    analogWrite(ENR, speed);
  } else if (motor == LEFT_MOTOR) {
    analogWrite(ENL, speed);
  }
}
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

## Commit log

2024-02-27 update: HAL reading and initial setup
    [LED_Blink_test.cfg]
2024-02-29 update: PID-Basic_tested_varification failed(motor issue)
    [LED_Blink_test.cfg]
2024-03-13 update: Box hole detection V1
2024-03-19 update: SLRC main code with separate file structure
    [SLRC ROBOT Debug.cfg]
2024-03-19 update: IR ARRAY code fixed
    [MotorControl.c, SLRC ROBOT.ioc, main.c]
2024-03-25 update: source codes
    [3.3V_LDO.SchDoc, Assem1.STEP - Base.STEP-1.STL, Assem1.STEP - Even newer spacer.STEP-1.STL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]
